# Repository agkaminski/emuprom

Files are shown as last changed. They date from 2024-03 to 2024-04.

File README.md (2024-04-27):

# emuprom
DIY ATmega8 based 27C256 EPROM emulator. Human accessible UART interface
(19200N1, CH340 on USB C).

Revision D has been verified and it is working as intended (working both with
TL866 EPROM programer and FellaPC computer).

# Target connection
Via ribbon cable with DIP-28 adapter. Uses 40 pin IDC connector, but only 28
pins are used. Target power state detection is supported (external bus is
resistant to the target high-z bus state).

Crude cable schematic, top view (should be enough to be able to make this cable):

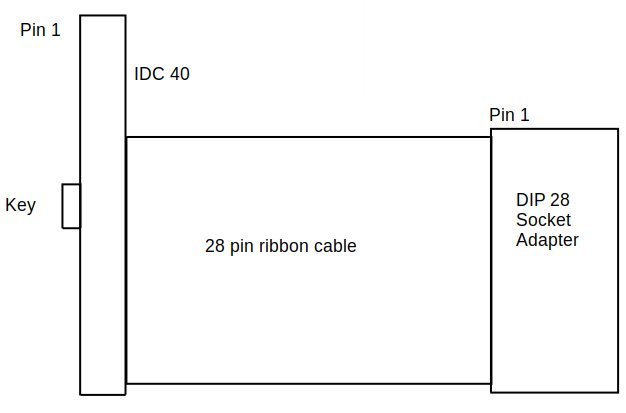
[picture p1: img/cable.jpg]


Sanity check - EPROM GND (pin \#14) should be on the one before last wire (bottom of the picture).

# UART interface
Available via USB C UART port, 19200 baud, no parity, 1 stop bit. Interface is
human friendly, but also easy to script. Available commands:

- ? - help
- ! - claim bus, memory edit, assert /RST
- . - release bus, deassert /RST
- @ - set address mode
- \# - set data mode
- = - dump 256 bytes @addres
- t - memory test
- \+ - echo on
- \- echo off
- m - calculate md5 sum
- s - clear memory (all 0xff)
- r - reset target (pulse /RST)

Example sequence with comments:
- \- echo disable,
- ! - claims the bus,
- @0000 - sets address to zero,
- \# - selects data mode,
- 0102030405060708 - 8 bytes are written at address 0,
- . - release the bus and start the target,
- \+ - enable echo.

Or all at once: -!@0000#0102030405060708.+

# Uploading FW
avr-gcc, avr-libc and avrdude are needed.

- make (build FW),
- make fuse (set fuses to set internal RC @8MHz),
- make install (upload FW).

# Pictures
This is a picture of revision D. Note the recommended heat shrink sleeve, to
prevent accidental short circuits.



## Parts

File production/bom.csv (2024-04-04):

Designator | Footprint | Quantity | Value | LCSC Part #
C1, C10, C11, C12, C13, C14, C2, C3, C4, C5, C6, C8, C9 | C_Disc_D3.0mm_W1.6mm_P2.50mm | 13 | 100n
J1 | IDC-Header_2x20_P2.54mm_Horizontal | 1 | Conn_02x20_Odd_Even
J2 | IDC-Header_2x03_P2.54mm_Vertical | 1 | Conn_02x03_Odd_Even
J3 | USB_C_Receptacle_GCT_USB4105-xx-A_16P_TopMnt_Horizontal | 1 | USB_C_Receptacle_USB2.0_14P
J4 | PinHeader_1x02_P2.54mm_Horizontal | 1 | Conn_01x02
R1, R4, R5, R6 | R_Axial_DIN0207_L6.3mm_D2.5mm_P7.62mm_Horizontal | 4 | 10K
R2, R3 | R_Axial_DIN0207_L6.3mm_D2.5mm_P7.62mm_Horizontal | 2 | 1K5
U1 | DIP-28_W15.24mm | 1 | CY62256-70PC
U10, U2, U3, U4 | DIP-20_W7.62mm | 4 | 74HC244
U11 | DIP-14_W7.62mm | 1 | 74HC02
U5 | DIP-14_W7.62mm | 1 | 74HC32
U6 | DIP-28_W7.62mm | 1 | ATmega8-16P
U7, U9 | DIP-20_W7.62mm | 2 | 74HC373
U8 | SOP-8_3.9x4.9mm_P1.27mm | 1 | CH340N

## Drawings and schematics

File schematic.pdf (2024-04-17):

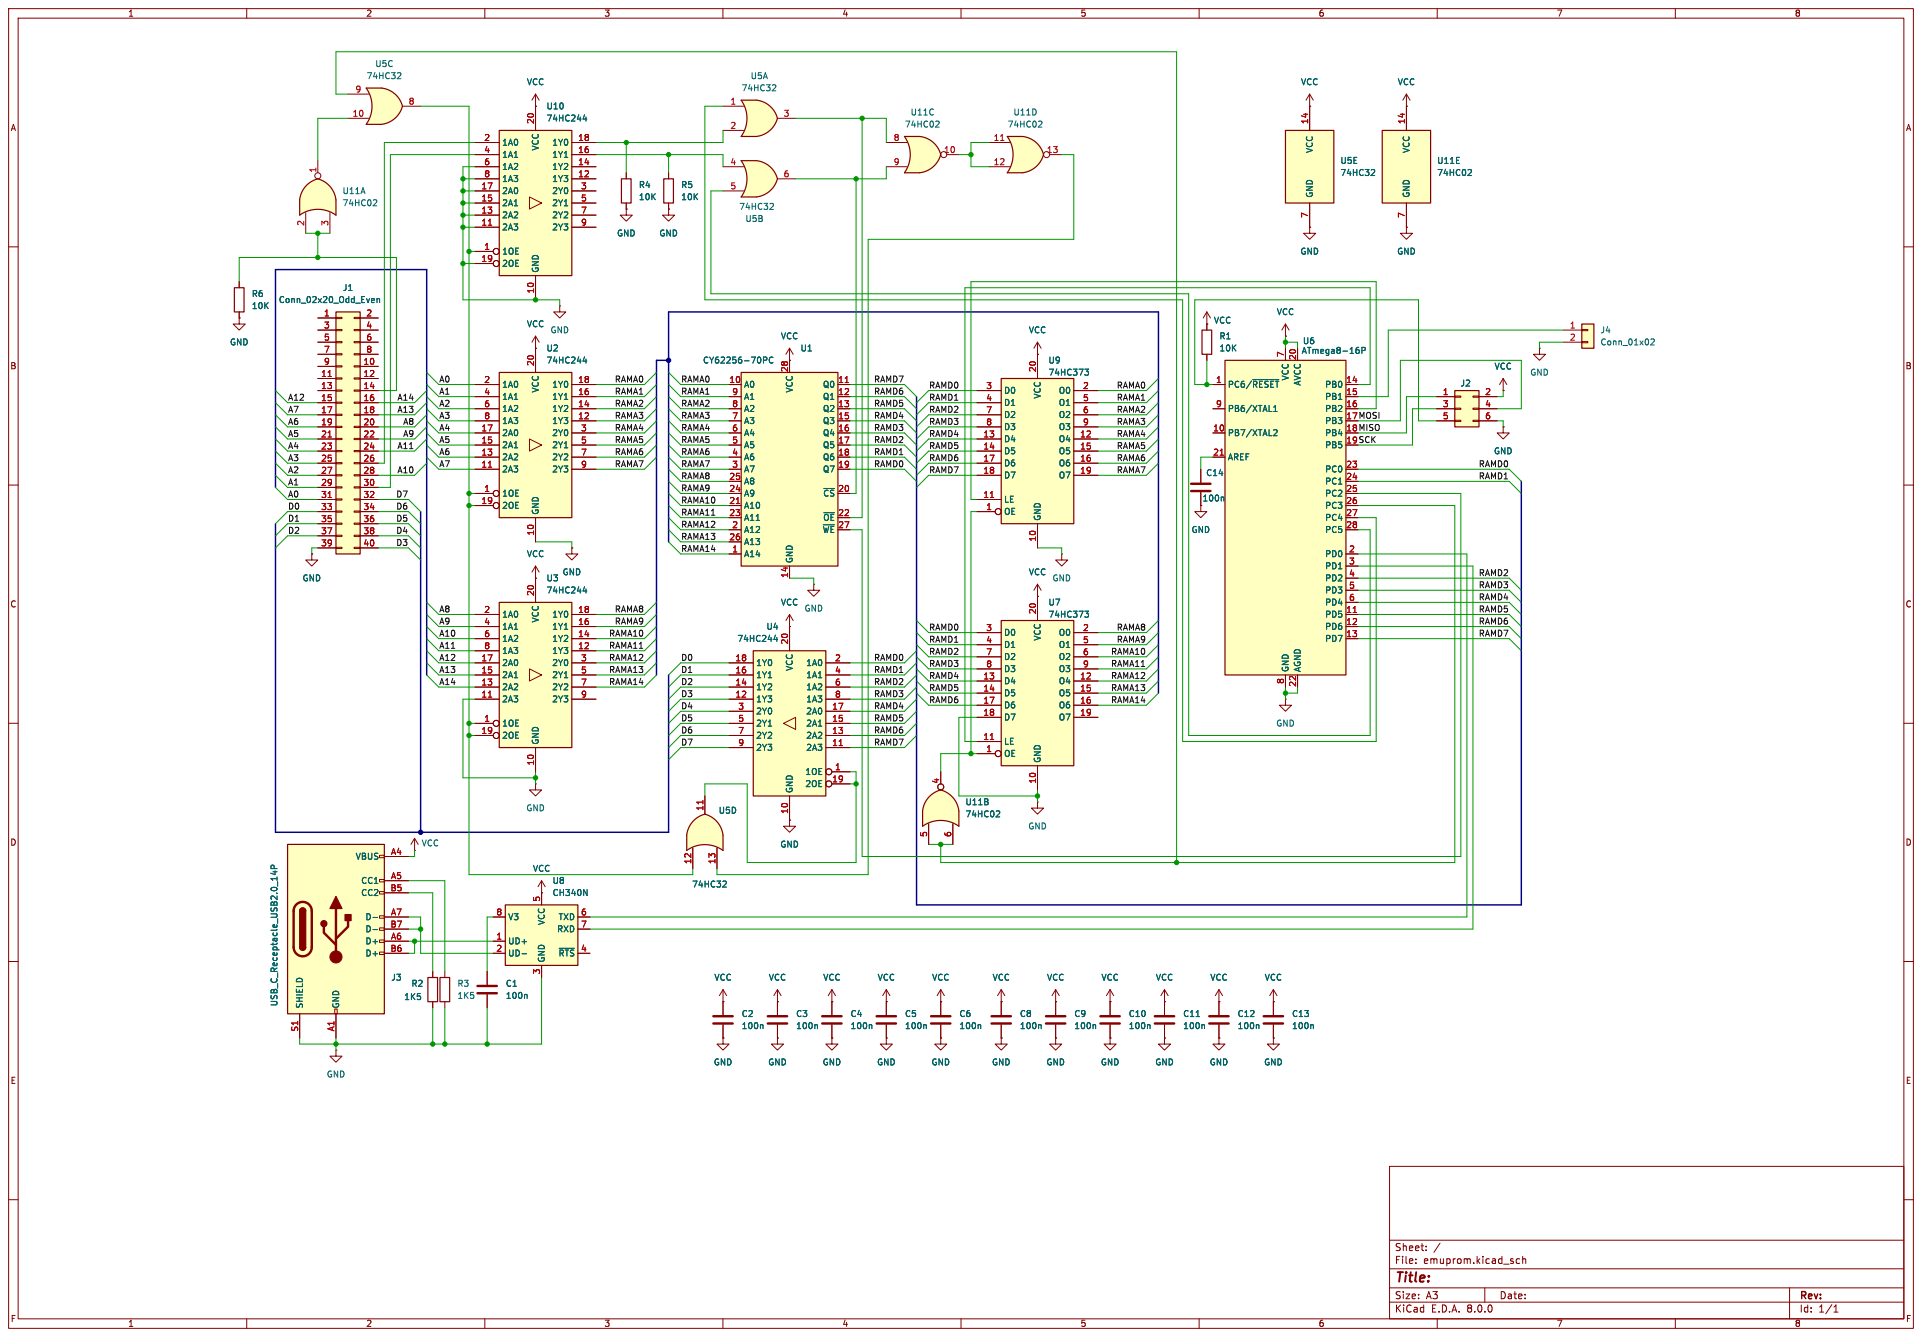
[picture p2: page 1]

Id: 1/1 Title: File: emuprom.kicad_sch Sheet: / C3

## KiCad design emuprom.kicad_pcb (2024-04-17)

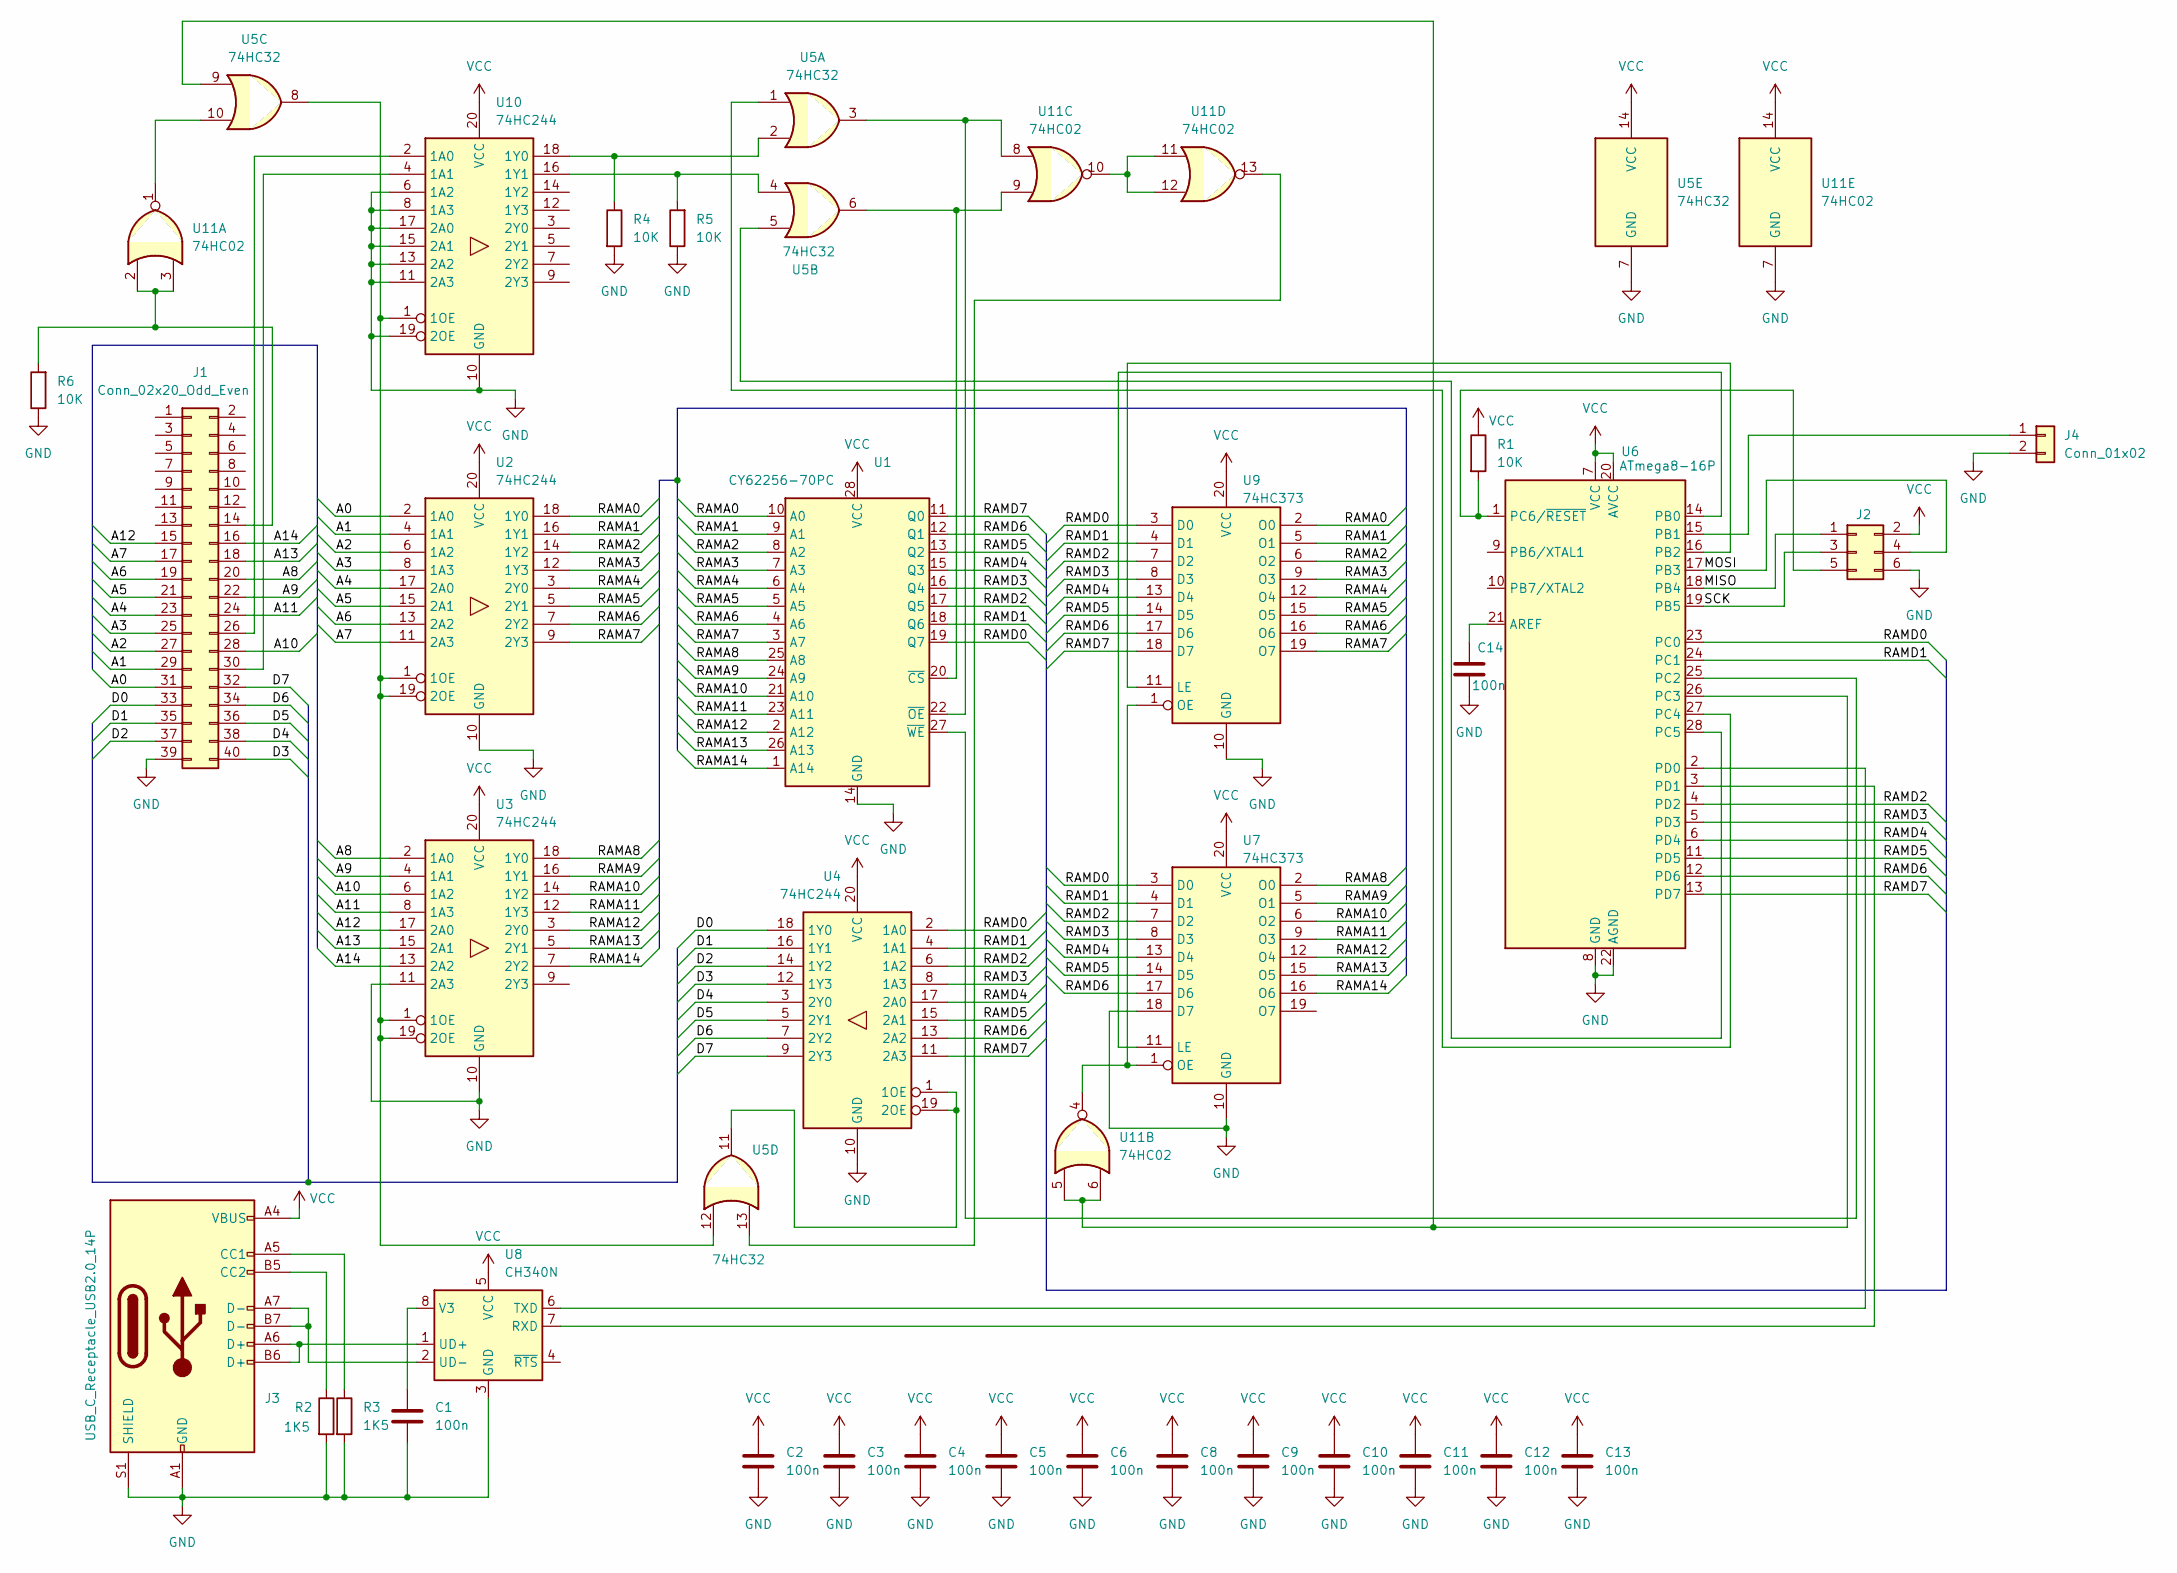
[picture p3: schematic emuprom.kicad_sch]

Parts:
C1, C2, C3, C4, C5, C6, C8, C9, C10, C11, C12, C13, C14: 100n; C_Disc_D3.0mm_W1.6mm_P2.50mm
J1: Conn_02x20_Odd_Even; IDC-Header_2x20_P2.54mm_Horizontal
J2: Conn_02x03_Odd_Even; IDC-Header_2x03_P2.54mm_Vertical
J3: USB_C_Receptacle_USB2.0_14P; USB_C_Receptacle_GCT_USB4105-xx-A_16P_TopMnt_Horizontal
J4: Conn_01x02; PinHeader_1x02_P2.54mm_Horizontal
R1, R4, R5, R6: 10K; R_Axial_DIN0207_L6.3mm_D2.5mm_P7.62mm_Horizontal
R2, R3: 1K5; R_Axial_DIN0207_L6.3mm_D2.5mm_P7.62mm_Horizontal
U1: CY62256-70PC; DIP-28_W15.24mm
U2, U3, U4, U10: 74HC244; DIP-20_W7.62mm
U5: 74HC32; DIP-14_W7.62mm
U6: ATmega8-16P; DIP-28_W7.62mm
U7, U9: 74HC373; DIP-20_W7.62mm
U8: CH340N; SOP-8_3.9x4.9mm_P1.27mm
U11: 74HC02; DIP-14_W7.62mm

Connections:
/A0: J1.31, U2.2 (1A0)
/A1: J1.29, U2.4 (1A1)
/A2: J1.27, U2.6 (1A2)
/A3: J1.25, U2.8 (1A3)
/A4: J1.23, U2.17 (2A0)
/A5: J1.21, U2.15 (2A1)
/A6: J1.19, U2.13 (2A2)
/A7: J1.17, U2.11 (2A3)
/A8: J1.20, U3.2 (1A0)
/A9: J1.22, U3.4 (1A1)
/A10: J1.28, U3.6 (1A2)
/A11: J1.24, U3.8 (1A3)
/A12: J1.15, U3.17 (2A0)
/A13: J1.18, U3.15 (2A1)
/A14: J1.16, U3.13 (2A2)
/D0: J1.33, U4.18 (1Y0)
/D1: J1.35, U4.16 (1Y1)
/D2: J1.37, U4.14 (1Y2)
/D3: J1.40, U4.12 (1Y3)
/D4: J1.38, U4.3 (2Y0)
/D5: J1.36, U4.5 (2Y1)
/D6: J1.34, U4.7 (2Y2)
/D7: J1.32, U4.9 (2Y3)
/MISO: J2.1, U6.18 (PB4)
/MOSI: J2.4, U6.17 (PB3)
/RAMA0: U1.10 (A0), U2.18 (1Y0), U9.2 (O0)
/RAMA1: U1.9 (A1), U2.16 (1Y1), U9.5 (O1)
/RAMA2: U1.8 (A2), U2.14 (1Y2), U9.6 (O2)
/RAMA3: U1.7 (A3), U2.12 (1Y3), U9.9 (O3)
/RAMA4: U1.6 (A4), U2.3 (2Y0), U9.12 (O4)
/RAMA5: U1.5 (A5), U2.5 (2Y1), U9.15 (O5)
/RAMA6: U1.4 (A6), U2.7 (2Y2), U9.16 (O6)
/RAMA7: U1.3 (A7), U2.9 (2Y3), U9.19 (O7)
/RAMA8: U1.25 (A8), U3.18 (1Y0), U7.2 (O0)
/RAMA9: U1.24 (A9), U3.16 (1Y1), U7.5 (O1)
/RAMA10: U1.21 (A10), U3.14 (1Y2), U7.6 (O2)
/RAMA11: U1.23 (A11), U3.12 (1Y3), U7.9 (O3)
/RAMA12: U1.2 (A12), U3.3 (2Y0), U7.12 (O4)
/RAMA13: U1.26 (A13), U3.5 (2Y1), U7.15 (O5)
/RAMA14: U1.1 (A14), U3.7 (2Y2), U7.16 (O6)
/RAMD0: U1.19 (Q7), U4.2 (1A0), U6.23 (PC0), U7.3 (D0), U9.3 (D0)
/RAMD1: U1.18 (Q6), U4.4 (1A1), U6.24 (PC1), U7.4 (D1), U9.4 (D1)
/RAMD2: U1.17 (Q5), U4.6 (1A2), U6.4 (PD2), U7.7 (D2), U9.7 (D2)
/RAMD3: U1.16 (Q4), U4.8 (1A3), U6.5 (PD3), U7.8 (D3), U9.8 (D3)
/RAMD4: U1.15 (Q3), U4.17 (2A0), U6.6 (PD4), U7.13 (D4), U9.13 (D4)
/RAMD5: U1.13 (Q2), U4.15 (2A1), U6.11 (PD5), U7.14 (D5), U9.14 (D5)
/RAMD6: U1.12 (Q1), U4.13 (2A2), U6.12 (PD6), U7.17 (D6), U9.17 (D6)
/RAMD7: U1.11 (Q0), U4.11 (2A3), U6.13 (PD7), U9.18 (D7)
/SCK: J2.3, U6.19 (PB5)
GND: C1.2, C2.2, C3.2, C4.2, C5.2, C6.2, C8.2, C9.2, C10.2, C11.2, C12.2, C13.2, C14.2, J1.39, J2.6, J3.A1 (GND), J3.A12 (GND), J3.B1 (GND), J3.B12 (GND), J3.S1 (SHIELD), J4.2, R2.2, R3.2, R4.2, R5.1, R6.1, U1.14 (GND), U2.10 (GND), U3.10 (GND), U3.11 (2A3), U4.10 (GND), U5.7 (GND), U6.8 (GND), U6.22 (AGND), U7.10 (GND), U7.18 (D7), U8.3 (GND), U9.10 (GND), U10.6 (1A2), U10.8 (1A3), U10.10 (GND), U10.11 (2A3), U10.13 (2A2), U10.15 (2A1), U10.17 (2A0), U10.19 (2OE), U11.7 (GND)
unnamed: J1.14, R6.2, U11.2, U11.3
unnamed: J1.26, U10.2 (1A0)
unnamed: J1.30, U10.4 (1A1)
unnamed: J2.5, R1.2, U6.1 (PC6/~RESET)
unnamed: J3.A5 (CC1), R3.1
unnamed: J3.B5 (CC2), R2.1
unnamed: J4.1, U6.15 (PB1)
unnamed: U1.20 (~CS), U5.6, U11.9
unnamed: U1.22 (~OE), U5.3, U11.8
unnamed: U1.27 (~WE), U6.25 (PC2)
unnamed: U4.1 (1OE), U4.19 (2OE), U5.11
unnamed: C14.1, U6.21 (AREF)
unnamed: U6.14 (PB0), U7.11 (LE)
unnamed: U6.16 (PB2), U9.11 (LE)
unnamed: U5.9, U6.26 (PC3), U11.5, U11.6
unnamed: U5.1, U6.27 (PC4)
unnamed: U5.5, U6.28 (PC5)
unnamed: U6.2 (PD0), U8.6 (TXD)
unnamed: U6.3 (PD1), U8.7 (RXD)
unnamed: U7.1 (OE), U9.1 (OE), U11.4
unnamed: J3.A6 (D+), J3.B6 (D+), U8.1 (UD+)
unnamed: J3.A7 (D-), J3.B7 (D-), U8.2 (UD-)
unnamed: C1.1, U8.8 (V3)
unnamed: U2.1 (1OE), U2.19 (2OE), U3.1 (1OE), U3.19 (2OE), U5.8, U5.12, U10.1 (1OE)
unnamed: R4.1, U5.2, U10.18 (1Y0)
unnamed: R5.2, U5.4, U10.16 (1Y1)
unnamed: U5.10, U11.1
unnamed: U11.10, U11.11, U11.12
unnamed: U5.13, U11.13
VCC: C2.1, C3.1, C4.1, C5.1, C6.1, C8.1, C9.1, C10.1, C11.1, C12.1, C13.1, J2.2, J3.A4 (VBUS), J3.A9 (VBUS), J3.B4 (VBUS), J3.B9 (VBUS), R1.1, U1.28 (VCC), U2.20 (VCC), U3.20 (VCC), U4.20 (VCC), U5.14 (VCC), U6.7 (VCC), U6.20 (AVCC), U7.20 (VCC), U8.5 (VCC), U9.20 (VCC), U10.20 (VCC), U11.14 (VCC)

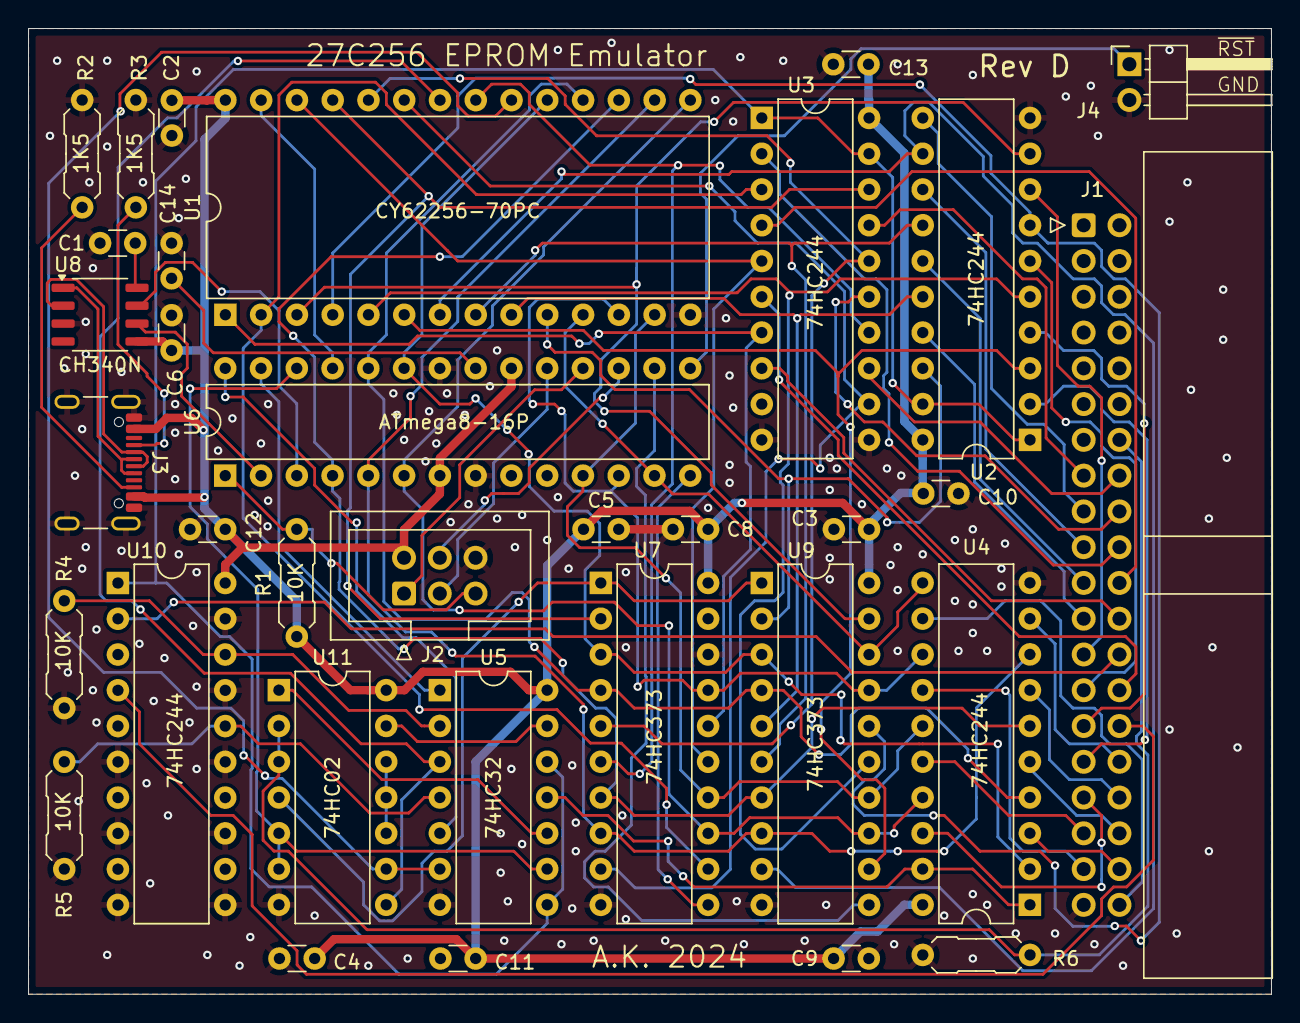
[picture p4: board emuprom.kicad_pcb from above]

Board: 2 copper layers, 88.3 x 68.6 mm, 34 parts (0 on the bottom side), 80 nets.

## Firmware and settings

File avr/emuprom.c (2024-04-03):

/*
 * PORTD[7..2] - PORTC[1..0]: data
 *
 * PORTB0: Latch Enable high
 * PORTB1: /RESET
 * PORTB2: Latch Enable low
 *
 * PORTC2: /WE
 * PORTC3: Claim sygnal (active high)
 * PORTC4: /OE
 * PORTC5: /CS
 *
 * PORTD0: RX
 * PORTD1: TX
 */

#include <avr/io.h>
#include <avr/interrupt.h>
#include <util/delay.h>

#include "uart/uart.h"
#include "md5/md5.h"

#include <stdint.h>
#include <stdbool.h>
#include <stdio.h>

static inline void nop(void)
{
	__asm__ volatile ("\tnop;");
}

#define SET(port, pin) ((port) |= (1 << (pin)))
#define CLEAR(port, pin) ((port) &= ~(1 << (pin)))
#define TOGGLE_HIGH(port, pin) \
	do { \
		nop(); \
		SET(port, pin); \
		nop(); \
		CLEAR(port, pin); \
		nop(); \
	} while (0)
#define TOGGLE_LOW(port, pin) \
	do { \
		nop(); \
		CLEAR(port, pin); \
		nop(); \
		SET(port, pin); \
		nop(); \
	} while (0)

static void claim(void)
{
	CLEAR(PORTB, 1);
	SET(DDRB, 1);
	SET(PORTC, 4);
	SET(PORTC, 3);
	DDRD |= 0xfc;
	DDRC |= 0x3;
}

static void release(void)
{
	DDRD &= ~0xfc;
	DDRC &= ~0x3;
	CLEAR(PORTC, 3);
	CLEAR(PORTC, 4);
	SET(DDRB, 1);
	SET(PORTB, 1);
}

static void setData(uint8_t data)
{
	uint8_t t = PORTC & ~(0x3);
	PORTC = t | (data & 0x3);
	t = PORTD & ~(0xfc);
	PORTD = t | (data & 0xfc);
	nop();
}

static uint8_t getData(void)
{
	uint8_t d = PINC & 0x3;
	d |= PIND & 0xfc;
	return d;
}

static void setAddr(uint16_t addr)
{
	setData(addr & 0xff);
	nop();
	TOGGLE_HIGH(PORTB, 2);
	nop();
	setData(addr >> 8);
	TOGGLE_HIGH(PORTB, 0);
	nop();
	setData(0);
}

static void write(uint16_t addr, uint8_t data)
{
	setAddr(addr);
	setData(data);
	nop();
	TOGGLE_LOW(PORTC, 2);
	nop();
	setData(0);
}

static uint8_t read(uint16_t addr)
{
	uint8_t ret = 0xff;

	setAddr(addr);
	DDRC &= ~0x3;
	DDRD &= ~0xfc;
	PORTC |= 0x3;
	PORTD |= 0xfc;
	nop();
	nop();
	nop();
	CLEAR(PORTC, 4);
	nop();
	ret = getData();
	SET(PORTC, 4);
	nop();
	DDRC |= 0x3;
	DDRD |= 0xfc;

	return ret;
}

static int memtest_fail(uint16_t addr, uint8_t expected, uint8_t got)
{
	char buff[40];
	sprintf(buff, "Fail @0x%04x (expected 0x%02x, got 0x%02x)\n",
		addr, expected, got);
	uart_puts(buff);
	return -1;
}

static void fill(uint8_t val)
{
	for (uint16_t addr = 0; addr < (32u * 1024); ++addr)
		write(addr, val);
}

static int test(uint8_t expected)
{
	for (uint16_t addr = 0; addr < (32u * 1024); ++addr) {
		uint8_t readback = read(addr);
		if (readback != expected) {
			return memtest_fail(addr, expected, readback);
		}
	}
	
	return 0;
}

static int memtest(void)
{
	fill(0);
	if (test(0)) return -1;
	fill(0x55);
	if (test(0x55)) return -1;
	fill(0xaa);
	if (test(0xaa)) return -1;
	fill(0xff);
	if (test(0xff)) return -1;

	return 0;
}

static void dump(uint16_t *addr)
{
	char buff[16];
	uint16_t i, j;

	for (i = 0; i < 256 && i + *addr < 32u * 1024; i += 16) {
		sprintf(buff, "%04x: ", i + *addr);
		uart_puts(buff);
		for (j = 0; j < 16; ++j) {
			uint8_t data = read(*addr + i + j);
			sprintf(buff, "%02x%s", data, (j != 15) ? ", " : "");
			uart_puts(buff);
		}
		uart_putc('\n');
	}
	
	*addr += i;
}

static void help(void)
{
	uart_puts("EPROM Emulator\nA.K. 2024\nCommands:\n");
	uart_puts("\t? - this help\n");
	uart_puts("\t! - claim bus, memory edit, assert /RST\n");
	uart_puts("\t. - release bus, deassert /RST\n");
	uart_puts("\t@ - set address mode\n");
	uart_puts("\t# - set data mode\n");
	uart_puts("\t= - dump 256 bytes @addres\n");
	uart_puts("\tt - memory test\n");
	uart_puts("\t+ - echo on\n");
	uart_puts("\t- - echo off\n");
	uart_puts("\tm - calculate md5 sum\n");
	uart_puts("\ts - clear memory (all 0xff)\n");
	uart_puts("\tr - reset target (pulse /RST)\n");
}

static void md5(void)
{
	MD5Context ctx;
	uint8_t buff[64];

	md5Init(&ctx);

	for (uint16_t i = 0; i < 32u * 1024; i += sizeof(buff)) {
		for (uint16_t j = 0; j < sizeof(buff); ++j) {
			buff[j] = read(i + j);
		}
		md5Update(&ctx, buff, sizeof(buff));
	}

	md5Finalize(&ctx);
	
	uart_puts("md5: ");
	for (uint8_t i = 0; i < sizeof(ctx.digest); ++i) {
		sprintf((char *)buff, "%02x", ctx.digest[i]);
		uart_puts((char *)buff);
	}
	uart_putc('\n');
}

static int parse(char c)
{
	static uint16_t addr;
	static uint8_t data;
	static uint8_t cnt;
	static enum { mode_addr, mode_data } mode = mode_data;
	static bool claimed = false;
	static int echoOff = 0;
	uint8_t val;
	int err;

	if ((c >= '0') && (c <= '9')) {
		val = c - '0';
	}
	else if ((c >= 'a') && (c <= 'f')) {
		val = c + 10 - 'a';
	}
	else if ((c >= 'A') && (c <= 'F')) {
		val = c + 10 - 'A';
	}
	else {
		switch (c) {
			case '!':
				claim();
				claimed = true;
				break;

			case '@':
				mode = mode_addr;
				cnt = 0;
				break;

			case '#':
				mode = mode_data;
				cnt = 0;
				break;

			case '.':
				release();
				claimed = false;
				break;

			case '=':
				if (claimed)
					dump(&addr);
				return -1; /* Supress echo */

			case '+':
				echoOff = 0;
				break;

			case '-':
				echoOff = 1;
				break;

			case 's':
				if (!claimed)
					return -1;
				fill(0xff);
				break;
				
			case 'r':
				CLEAR(PORTB, 1);
				SET(DDRB, 1);
				_delay_ms(100);
				CLEAR(DDRB, 1);
				SET(PORTB, 1);
				break;

			case 'm':
				if (claimed)
					md5();
				return -1; /* Supress echo */

			case '?':
				help();
				return -1; /* Supress echo */

			case 't':
				err = claimed ? memtest() : -1;
				if (!err) {
					uart_puts("Memory OK\n");
				}
				return -1; /* Supress echo */

			default:
				return -1;
		}

		return echoOff;
	}

	if (mode == mode_addr) {
		addr = (addr << 4) | val;
	}
	else {
		data = (data << 4) | val;
		if (++cnt > 1) {
			if (claimed)
				write(addr, data);
			addr++;
			cnt = 0;
		}
	}

	return echoOff;
}

int main(void)
{
	DDRB = 0x7;
	DDRC = 0x3c;
	DDRD = 1 << 1;

	PORTB = 0x2;
	PORTC = 1 << 2;
	PORTD = 0;
	
	claim();

	uart_init(26); /* 19200 */
	sei();
	
	fill(0xff);
	help();
	
	release();

	while (1) {
		int rx;
		do {
			rx = uart_getc();
		} while ((rx & ~0xff) != 0);
		
		if (!parse(rx & 0xff)) {
			uart_putc(rx & 0xff);
		}
	}

	return 0;
}

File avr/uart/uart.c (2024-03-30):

/*************************************************************************
Title:    Interrupt UART library with receive/transmit circular buffers
Author:   Peter Fleury <pfleury@gmx.ch>   http://tinyurl.com/peterfleury
File:     $Id: uart.c,v 1.15.2.4 2015/09/05 18:33:32 peter Exp $
Software: AVR-GCC 4.x
Hardware: any AVR with built-in UART, 
License:  GNU General Public License 
          
DESCRIPTION:
    An interrupt is generated when the UART has finished transmitting or
    receiving a byte. The interrupt handling routines use circular buffers
    for buffering received and transmitted data.
    
    The UART_RX_BUFFER_SIZE and UART_TX_BUFFER_SIZE variables define
    the buffer size in bytes. Note that these variables must be a 
    power of 2.
    
USAGE:
    Refere to the header file uart.h for a description of the routines. 
    See also example test_uart.c.

NOTES:
    Based on Atmel Application Note AVR306
                    
LICENSE:
    Copyright (C) 2015 Peter Fleury, GNU General Public License Version 3

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
*************************************************************************/
#include <avr/io.h>
#include <avr/interrupt.h>
#include <avr/pgmspace.h>
#include "uart.h"


/*
 *  constants and macros
 */

/* size of RX/TX buffers */
#define UART_RX_BUFFER_MASK ( UART_RX_BUFFER_SIZE - 1)
#define UART_TX_BUFFER_MASK ( UART_TX_BUFFER_SIZE - 1)

#if ( UART_RX_BUFFER_SIZE & UART_RX_BUFFER_MASK )
#error RX buffer size is not a power of 2
#endif
#if ( UART_TX_BUFFER_SIZE & UART_TX_BUFFER_MASK )
#error TX buffer size is not a power of 2
#endif


#if defined(__AVR_AT90S2313__) || defined(__AVR_AT90S4414__) || defined(__AVR_AT90S8515__) || \
    defined(__AVR_AT90S4434__) || defined(__AVR_AT90S8535__) || \
    defined(__AVR_ATmega103__)
 /* old AVR classic or ATmega103 with one UART */
 #define UART0_RECEIVE_INTERRUPT   UART_RX_vect 
 #define UART0_TRANSMIT_INTERRUPT  UART_UDRE_vect
 #define UART0_STATUS      USR
 #define UART0_CONTROL     UCR
 #define UART0_DATA        UDR  
 #define UART0_UDRIE       UDRIE
 #define UART0_UBRRL       UBRR
 #define UART0_BIT_U2X     U2X
 #define UART0_BIT_RXCIE   RXCIE
 #define UART0_BIT_RXEN    RXEN
 #define UART0_BIT_TXEN    TXEN
#elif defined(__AVR_AT90S2333__) || defined(__AVR_AT90S4433__)
 /* old AVR classic with one UART */
 #define UART0_RECEIVE_INTERRUPT   UART_RX_vect 
 #define UART0_TRANSMIT_INTERRUPT  UART_UDRE_vect
 #define UART0_STATUS      UCSRA
 #define UART0_CONTROL     UCSRB
 #define UART0_DATA        UDR 
 #define UART0_UDRIE       UDRIE
 #define UART0_UBRRL       UBRR
 #define UART0_BIT_U2X     U2X
 #define UART0_BIT_RXCIE   RXCIE
 #define UART0_BIT_RXEN    RXEN
 #define UART0_BIT_TXEN    TXEN
#elif defined(__AVR_AT90PWM216__) || defined(__AVR_AT90PWM316__) 
 /* AT90PWN216/316 with one USART */
 #define UART0_RECEIVE_INTERRUPT   USART_RX_vect
 #define UART0_TRANSMIT_INTERRUPT  USART_UDRE_vect
 #define UART0_STATUS      UCSRA
 #define UART0_CONTROL     UCSRB
 #define UART0_CONTROLC    UCSRC
 #define UART0_DATA        UDR
 #define UART0_UDRIE       UDRIE
 #define UART0_UBRRL       UBRRL
 #define UART0_UBRRH       UBRRH
 #define UART0_BIT_U2X     U2X
 #define UART0_BIT_RXCIE   RXCIE
 #define UART0_BIT_RXEN    RXEN
 #define UART0_BIT_TXEN    TXEN
 #define UART0_BIT_UCSZ0   UCSZ0
 #define UART0_BIT_UCSZ1   UCSZ1 
#elif defined(__AVR_ATmega8__) || defined(__AVR_ATmega8A__) || \
      defined(__AVR_ATmega16__) || defined(__AVR_ATmega16A__) || \
      defined(__AVR_ATmega32__) || defined(__AVR_ATmega32A__) || \
      defined(__AVR_ATmega323__)
 /* ATmega with one USART */
 #define UART0_RECEIVE_INTERRUPT   USART_RXC_vect
 #define UART0_TRANSMIT_INTERRUPT  USART_UDRE_vect
 #define UART0_STATUS      UCSRA
 #define UART0_CONTROL     UCSRB
 #define UART0_CONTROLC    UCSRC
 #define UART0_DATA        UDR
 #define UART0_UDRIE       UDRIE
 #define UART0_UBRRL       UBRRL
 #define UART0_UBRRH       UBRRH
 #define UART0_BIT_U2X     U2X
 #define UART0_BIT_RXCIE   RXCIE
 #define UART0_BIT_RXEN    RXEN
 #define UART0_BIT_TXEN    TXEN
 #define UART0_BIT_UCSZ0   UCSZ0
 #define UART0_BIT_UCSZ1   UCSZ1
 #define UART0_BIT_URSEL   URSEL
#elif defined (__AVR_ATmega8515__) || defined(__AVR_ATmega8535__)
 #define UART0_RECEIVE_INTERRUPT   USART_RX_vect
 #define UART0_TRANSMIT_INTERRUPT  USART_UDRE_vect
 #define UART0_STATUS      UCSRA
 #define UART0_CONTROL     UCSRB
 #define UART0_CONTROLC    UCSRC 
 #define UART0_DATA        UDR
 #define UART0_UDRIE       UDRIE
 #define UART0_UBRRL       UBRRL
 #define UART0_UBRRH       UBRRH
 #define UART0_BIT_U2X     U2X
 #define UART0_BIT_RXCIE   RXCIE
 #define UART0_BIT_RXEN    RXEN
 #define UART0_BIT_TXEN    TXEN
 #define UART0_BIT_UCSZ0   UCSZ0
 #define UART0_BIT_UCSZ1   UCSZ1
 #define UART0_BIT_URSEL   URSEL
#elif defined(__AVR_ATmega163__)
  /* ATmega163 with one UART */
 #define UART0_RECEIVE_INTERRUPT   UART_RX_vect
 #define UART0_TRANSMIT_INTERRUPT  UART_UDRE_vect
 #define UART0_STATUS      UCSRA
 #define UART0_CONTROL     UCSRB
 #define UART0_DATA        UDR
 #define UART0_UDRIE       UDRIE
 #define UART0_UBRRL       UBRR
 #define UART0_UBRRH       UBRRHI
 #define UART0_BIT_U2X     U2X
 #define UART0_BIT_RXCIE   RXCIE
 #define UART0_BIT_RXEN    RXEN
 #define UART0_BIT_TXEN    TXEN
#elif defined(__AVR_ATmega162__) 
 /* ATmega with two USART */
 #define ATMEGA_USART1
 #define UART0_RECEIVE_INTERRUPT   USART0_RXC_vect
 #define UART1_RECEIVE_INTERRUPT   USART1_RXC_vect
 #define UART0_TRANSMIT_INTERRUPT  USART0_UDRE_vect
 #define UART1_TRANSMIT_INTERRUPT  USART1_UDRE_vect
 #define UART0_STATUS      UCSR0A
 #define UART0_CONTROL     UCSR0B
 #define UART0_CONTROLC    UCSR0C
 #define UART0_DATA        UDR0
 #define UART0_UDRIE       UDRIE0
 #define UART0_UBRRL       UBRR0L
 #define UART0_UBRRH       UBRR0H
 #define UART0_BIT_URSEL   URSEL0
 #define UART0_BIT_U2X     U2X0
 #define UART0_BIT_RXCIE   RXCIE0
 #define UART0_BIT_RXEN    RXEN0
 #define UART0_BIT_TXEN    TXEN0
 #define UART0_BIT_UCSZ0   UCSZ00
 #define UART0_BIT_UCSZ1   UCSZ01
 #define UART1_STATUS      UCSR1A
 #define UART1_CONTROL     UCSR1B
 #define UART1_CONTROLC    UCSR1C
 #define UART1_DATA        UDR1
 #define UART1_UDRIE       UDRIE1
 #define UART1_UBRRL       UBRR1L
 #define UART1_UBRRH       UBRR1H
 #define UART1_BIT_URSEL   URSEL1
 #define UART1_BIT_U2X     U2X1
 #define UART1_BIT_RXCIE   RXCIE1
 #define UART1_BIT_RXEN    RXEN1
 #define UART1_BIT_TXEN    TXEN1
 #define UART1_BIT_UCSZ0   UCSZ10
 #define UART1_BIT_UCSZ1   UCSZ11 
#elif defined(__AVR_ATmega161__)
 /* ATmega with UART */
 #error "AVR ATmega161 currently not supported by this libaray !"
#elif defined(__AVR_ATmega169__)
 /* ATmega with one USART */
 #define UART0_RECEIVE_INTERRUPT   USART0_RX_vect
 #define UART0_TRANSMIT_INTERRUPT  USART0_UDRE_vect
 #define UART0_STATUS      UCSRA
 #define UART0_CONTROL     UCSRB
 #define UART0_CONTROLC    UCSRC
 #define UART0_DATA        UDR
 #define UART0_UDRIE       UDRIE
 #define UART0_UBRRL       UBRRL
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

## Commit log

2024-03-30 Initial import
    [bom.csv, designators.csv, emuprom.kicad_pcb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]
2024-04-03 Fix HW bug
    U4 direction pin was tied to the wrong signal -
    should be /RD instead of /WR. Tied it to the ground
    instead. Now U4 74HC245 should be replaced with
    74HC244, but it would require big layout change, so
    I'm leaving it as is.
    [bom.csv, designators.csv, emuprom.kicad_pcb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]
2024-04-03 Add adapter cable info and update readme
2024-04-04 Revision C: redesign to fix U4 problem
    Reduced PCB footprint slightly, change U11 74HC04 -> 74HC02
    [bom.csv, emuprom.kicad_pcb, emuprom.kicad_sch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]
2024-04-17 rev D: Fix U4 output being swapped with input
    [bom.csv, designators.csv, emuprom.kicad_pcb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]
